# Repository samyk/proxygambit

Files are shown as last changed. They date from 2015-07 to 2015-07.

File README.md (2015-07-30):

# [ProxyGambit](http://samy.pl/proxygambit)

**ProxyGambit** is a simple anonymization device that allows you to access the Internet **from anywhere in the world** without revealing your true location or IP, fracturing your traffic from the Internet/IP through either a long distance radio link or a reverse tunneled GSM bridge that ultimately drops back onto the Internet and exits through a wireless network you're no where near.

While a point to point link is supported, the reverse GSM-to-TCP bridge allows you to proxy from thousands of miles away with nothing other than a computer and Internet with no direct link back to your originating machine.

ProxyGambit Directional Antenna to Laptop (http://samy.pl/proxygambit/laptopbig.png)

A high speed (150Mbps+) link is available with direct line of sight from 10km+ away, or if further away, a 2G GSM connection produces a **reverse TCP tunnel serializing a shell** into the device accessible from anywhere in the world via the Internet or GSM. Either method **proxies your connection through local wifi networks near the device**, shielding and making it more difficult to determine your true location, IP and identity.

ProxyGambit is an improvement and reincarnation of [ProxyHam](http://www.wired.com/2015/07/online-anonymity-project-proxyham-mysteriously-vanishes/), the promising device that was to debut at Defcon 2015, yet [vanished with no source, documentation or reason for its "destruction"](http://www.wired.com/2015/07/online-anonymity-project-proxyham-mysteriously-vanishes/). ProxyHam *"promised to mask your location online by putting you up to 2.5 miles away from your router"*

ProxyGambit improves upon ProxyHam not only by allowing a greater direct range, but also enables you to proxy from **anywhere in the world using just an Internet connection, which can then proxy through a reverse GSM serial link onto a public wifi network**.

Once set up, no special hardware is needed to bridge through the GSM link and back out onto wifi -- just you, a computer and a net connection (which will not be as easily identified.)

> This is an insecure, bare bones proof of concept. The fragmentation of data through alternate mediums is a useful and effective concept and those interested in privacy, anonymization, or deanonymization should explore this area further. Entropy is both gained and lost with these methods and many risks are involved when deploying any system of this nature.

by [@SamyKamkar](https://twitter.com/samykamkar) // <code@samy.pl> // <http://samy.pl> // Jul 14, 2015

Code available on [github](https://github.com/samyk/proxygambit), Linux image available [here](https://mega.nz/#!5JAzTKjC!XUlpWcnsqpTOUtU_-QY0lh7gy-hE9gf1rZyPa2IsFdQ)

------

# Hardware

ProxyGambit Hardware (http://samy.pl/proxygambit/allbig.png)

### Raspberry Pi
**$35**: A [Raspberry Pi 2 Model B](http://amzn.to/1TCfkO1) (or cheaper [RPi Model B+](http://amzn.to/1f33DAL)) computer is a critical portion of the core and drives the Linux serial link while also bridging our public wifi to radio connection.

```
username: pi
password: donttracemebro
```

### Arduino
**$8**: Any ATmega328 device will suffice, such as my favorite [Arduino Nano](http://amzn.to/1f33WM2), which provides a software proxy layer between the serial UART of the Raspberry Pi and the FONA GSM board. A logic level converter or voltage divider is required to prevent imminent destruction of hardware which we perform with a few inexpensive resistors.

### FONA GSM Board
**$40**: The [Adafruit FONA GSM board](http://amzn.to/1SmM1N9) uses a SIM800 chip which allows us to connect an Arduino to GSM, providing us a 2G Internet link, and can additionally allow SMSs and voice calls to our friends to verify whether their refrigerators are running.

ProxyGambit Raspberry Pi with Arduino (http://samy.pl/proxygambit/IMG_3138.JPG)

### FONA Antenna
**$6**: An [antenna](http://amzn.to/1IZLDDt) is helfpul (read: necessary).

### Point-to-Point Wireless Links
**$98**: For low cost and low profile, I suggest either a **pair** of the [Ubiquiti NanoStation LocoM2s](http://amzn.to/1GlBsmn) (2.4GHz) which reach 5km+, or a **pair** of the [Ubiquiti NanoStation LocoM5s](http://amzn.to/1GlBqep) (5GHz) which reach 10km+, but are slightly more expensive at $62 or $124 for both. These devices are not interchangeable. Additionally, if you choose the LocoM5, you can actually use one of the devices to acquire Internet access at Burning Man.

### Wifi Card
**$10**: You can use anything such as an [Edimax](http://amzn.to/1f34zVV) adapter, or a more powerful [Alfa AWUS036NH](http://amzn.to/1SmMi2x) adapter. This all depends on how far you'd like your ProxyGambit device to reach. This is specifically to connect to the "exit node" of the proxy link where your Internet traffic will ultimately come out of and appear to be coming from.

### SIM Card
**$8**: You will need a [SIM card](http://amzn.to/1GlBz1w) with access to a 2G network. You can purchase prepaid SIM cards in cash with 2G through [T-Mobile](http://amzn.to/1GlBz1w).

### SD Card
**$6**: An [SD card](http://amzn.to/1f352XW) is required for the Raspberry Pi to host the operating system and data.

### Powered USB Hub
**$10**: I avoid two issues with Raspberry Pi -- the limited power output from USB, and the limited power input from most USB power supplies. I do this by using a [2.5A powered USB hub](http://amzn.to/1TCg0D3) in a virtual loop. The hub acts as the power supply for the Raspberry Pi, preventing any need for a power supply, while ironically I connect the source of the hub back into one of the Raspberry Pi USB slots. This may appear dangerous as a voltage or data loop, but the Pi's USB-voltage-in has data lines split off, and the USB hub prefers power from its voltage rectifier rather than the recirculated power lines.

Raspberry Pi USB Hub Power Loop (http://samy.pl/proxygambit/loopdescbig.png)

### 3.7 Lithium-Ion (LiOn or LiPo) Battery
**$13**: The FONA GSM board annoyingly requires a 3.4-4.0V voltage source in addition to a 5V source, so I use a small [lipo battery](http://amzn.to/1TCg71t) for this. The FONA has a built-in charger so I tie the charger directly to the 5V from the Arduino, which actually bypasses the Arduino voltage regulator and instead grabs power from our high-current USB hub.

-----

# Software

Code @ <https://github.com/samyk/proxygambit> & [Linux image here](https://mega.nz/#!5JAzTKjC!XUlpWcnsqpTOUtU_-QY0lh7gy-hE9gf1rZyPa2IsFdQ)

### ProxyGambit (Arduino + GSM Link)
The microcontroller code produces a serial connection over a reverse TCP tunnel through a 2G GSM link and ties it to the UART serial lines of the Raspberry Pi. Compile this onto your Arduino, but be sure to change the TCP_PORT and TCP_HOST definitions in pg_gsm_avr.ino to connect to your own server. We abuse the fact that the SIM800 GSM chip allows only outbound TCP connections and produce a reverse tunnel. The hardware serial lines are hardwired (with a voltage divider) to the Raspberry Pi's serial, and we employ software serial to communicate to the FONA board.

### FONA
We use the Adafruit [FONA](https://github.com/adafruit/Adafruit_FONA_Library) library to produce an outbound TCP connection over the 2G GSM/GPRS link. This actually allows a reverse tunnel back in which we link to serial.

### Raspberry Pi Linux Image w/Network Bridging + UART
We use Raspberry Pi Wheezy (2015-05-05) image with network bridging via [bridge-utils](https://packages.debian.org/search?keywords=bridge-utils) and serial UART enabled to communicate with our microcontroller. Make sure to set up the wifi connection you want to use via `/etc/wpa_supplicant/wpa_supplicant.conf`, or you can serial in over GSM later on to connect to a network.

### netcat
The SIM800 is not able to open listening sockets, but is capable of making outbound TCP connections. We abuse this property to bridge traffic that was once IP into GSM traffic, but upon retrieval, we tunnel it back into IP through an entirely different, unrelated and physically separated network (the exit wifi node).

From your own server (defined in pg_gsm_avr.ino), run:

`nc -vlp 1337 # listens verbosely on port 1337`

-----

ProxyGambit Arduino (http://samy.pl/proxygambit/IMG_3139.JPG)

# Wiring

Available from [github](https://github.com/samyk/proxygambit)

* Use a ~1.6k resistor between RPi RX and Arduino TX and a ~3.3k resistor between RPi RX and Arduino ground
* Connect lipo and antenna to FONA
* Power RPi from USB hub
* Send main USB hub cable into any RPi USB port
* Connect wifi card to USB hub
* Connect Ubiquiti to RPi ethernet

ProxyGambit Arduino (http://samy.pl/proxygambit/proxygambit_bbbig.png)

-----

# Contact

Contact on Twitter: [@SamyKamkar](https://twitter.com/samykamkar)

More projects at <http://samy.pl> or reachable @ <code@samy.pl>

------

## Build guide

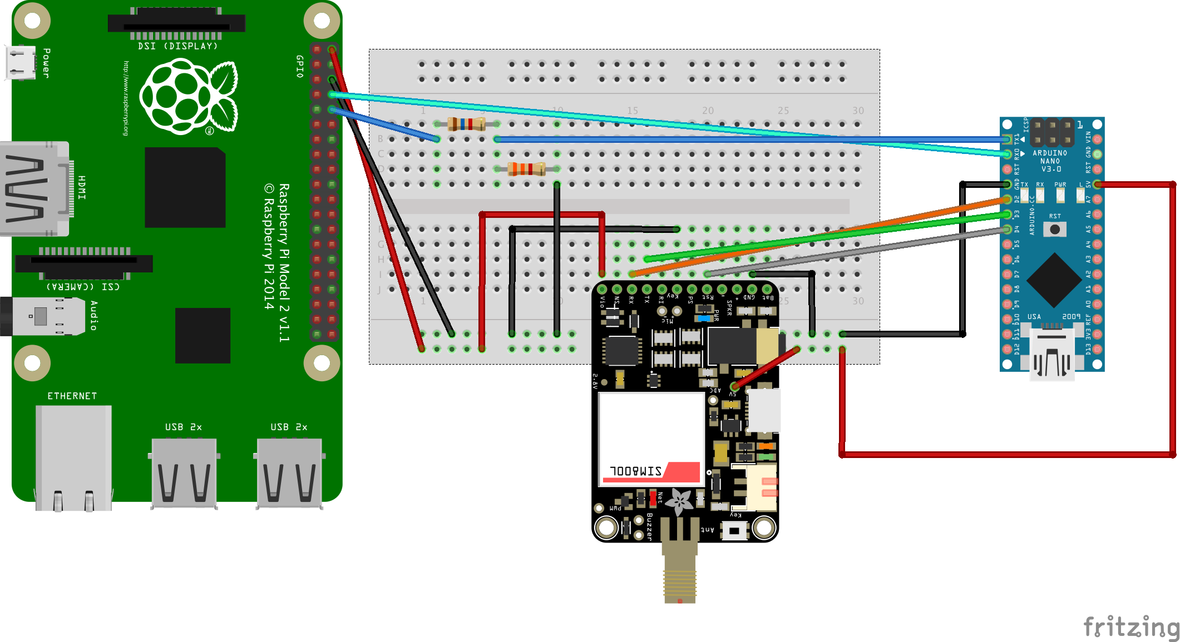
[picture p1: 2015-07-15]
wiring.png

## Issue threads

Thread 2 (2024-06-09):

possibel to use 3G sim card

zen-011, 2024-06-09:
hi i have some questions about the proxy gambit .
is it possible to use a 3G sim card instead of a 2G one?
and the FONA GSM board is available in european version, can i just replace it and do i have to change something in the software or can i use it 1:1?

samyk, 2024-06-09:
You can use the [FONA 3G](https://www.adafruit.com/product/2687) version, the code may need some minor changes.

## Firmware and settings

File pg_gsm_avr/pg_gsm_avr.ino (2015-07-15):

/*
 * ProxyGambit (GSM portion) -
 *   provides a serial terminal to a Raspberry Pi over a
 *   reverse TCP shell through a 2G GSM connection (SIM card)
 *
 * Hardware requirements:
 *   Raspberry Pi (or other serialized device)
 *   Arduino (ATmega328)
 *   Adafruit FONA (GSM board)
 *   SIM card (2G/GPRS enabled)
 *   Resistors (~1.6k and ~3.3k)
 *   3.4-4V or LiPo battery
 *   USB WiFi adapter for RPi
 *   SD card for RPi
 *
 * by Samy Kamkar
 * http://samy.pl
 */

// CHANGE YOUR TCP_PORT AND TCP_HOST TO CONNECT OUT TO YOUR MACHINE
// From your machine, you can then run:
//  nc -vlp 1337
#define TCP_PORT 1337
#define TCP_HOST "samy.pl"
#define TCP_HOST_MAXLEN 50

#include "Adafruit_FONA.h"

#define FONA_RX 2
#define FONA_TX 3
#define FONA_RST 4

char tcpserver[TCP_HOST_MAXLEN+1];

// This is to handle the absence of software serial on platforms
// like the Arduino Due. Modify this code if you are using different
// hardware serial port, or if you are using a non-avr platform
// that supports software serial.
#ifdef __AVR__
  #include <SoftwareSerial.h>
  SoftwareSerial fonaSS = SoftwareSerial(FONA_TX, FONA_RX);
  SoftwareSerial *fonaSerial = &fonaSS;
#else
  HardwareSerial *fonaSerial = &Serial1;
#endif

Adafruit_FONA fona = Adafruit_FONA(FONA_RST);

uint8_t readline(char *buff, uint8_t maxbuff, uint16_t timeout = 0);

void setup() {
  fonaSerial->begin(4800);
  if (! fona.begin(*fonaSerial)) {
//    Serial.println(F("Couldn't find FONA"));
    while(1);
  }
//  Serial.println(F("FONA is OK"));

  fona.enableGPRS(true);

  // Print SIM card IMEI number.
  char imei[15] = {0}; // MUST use a 16 character buffer for IMEI!
  uint8_t imeiLen = fona.getIMEI(imei);
  if (imeiLen > 0) {
//    Serial.print("SIM card IMEI: "); Serial.println(imei);
  }
  
  strncpy(tcpserver, TCP_HOST, TCP_HOST_MAXLEN);

  // Optionally configure a GPRS APN, username, and password.
  // You might need to do this to access your network's GPRS/data
  // network.  Contact your provider for the exact APN, username,
  // and password values.  Username and password are optional and
  // can be removed, but APN is required.
  //fona.setGPRSNetworkSettings(F("your APN"), F("your username"), F("your password"));
  Serial.begin(115200);
}

#define MAXBUFLEN 80
uint8_t rbyte;
char buf[MAXBUFLEN];
bool conn;
void loop() {
  int j = 0;

  // reconnect if disconnected
  if (!fona.TCPconnected())
  {
    conn = fona.TCPconnect(tcpserver, TCP_PORT);
//    Serial.println(conn ? "success" : "FAIL");
    if (!conn)
    {
//      Serial.println("Waiting 1 second to try again");
      delay(1000);
    }
  }
  
  else
  {
    //Serial.println("connected");
    // tcp (user) data to read?
    while (fona.TCPavailable())
    {
 //     Serial.println("tcp avail");
      // send to raspi (and serial)
      fona.TCPread((uint8_t*)buf, MAXBUFLEN);
      Serial.print((char*)buf);
    }
    
    // raspi data?
    while (Serial.available())
    {
      j = 0;
      while (Serial.available() && j < MAXBUFLEN-2)
      {
        buf[j++] = Serial.read();
//        rbyte = Serial.read();
//        sprintf(buf+j, "%02X", rbyte);
//        j += 2;
      }
      buf[j] = '\0';
      fona.TCPsend((char*)buf, j);
    }
  }
}
